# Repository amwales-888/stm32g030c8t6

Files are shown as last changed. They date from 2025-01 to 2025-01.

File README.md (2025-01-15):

# stm32g030c8t6
Simple breakout board for stm32g030c8t6

- 3.3v LDO powered from 5V USB.
- UART connectivity to USB via ch340 optionally connected to pins PA9/PA10 using jumpers.
- ARM SWD programming interface header.
- All other pins are broken out to headers.
- 1 LEDS optionally connected to pin PB0 using jumper.
- 1 Button with pulldown optionally connected to pin PB1 using jumper.
- 1 Button connected to RESET pin, pulled high.

<table>
  <tr>
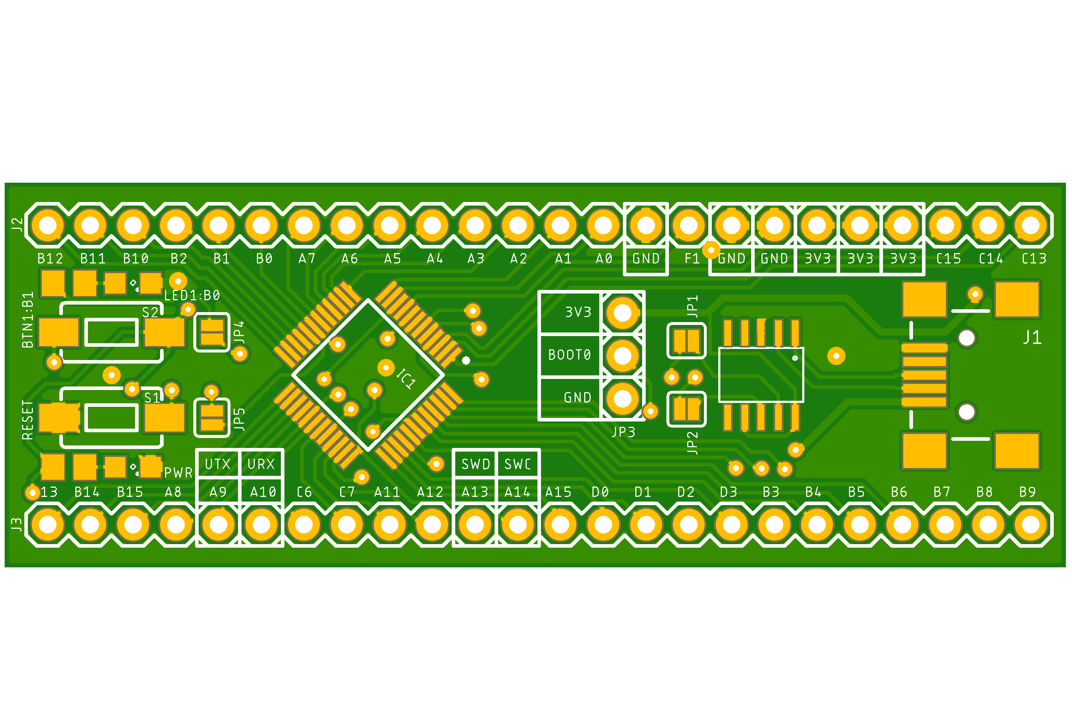
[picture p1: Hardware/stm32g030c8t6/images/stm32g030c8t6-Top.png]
    <td> </td>
  </tr>
  <tr>
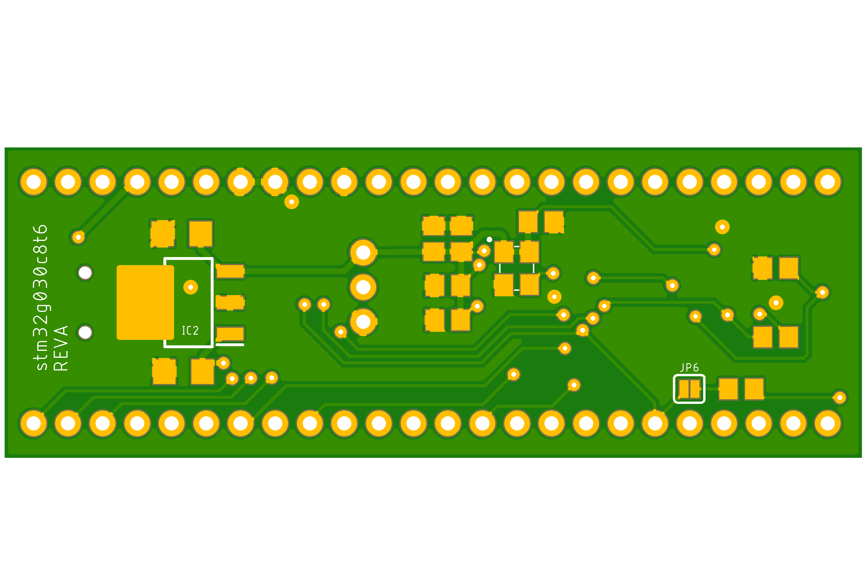
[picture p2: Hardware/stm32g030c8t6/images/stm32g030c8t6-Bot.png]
    <td> </td>
  </tr>
</table>

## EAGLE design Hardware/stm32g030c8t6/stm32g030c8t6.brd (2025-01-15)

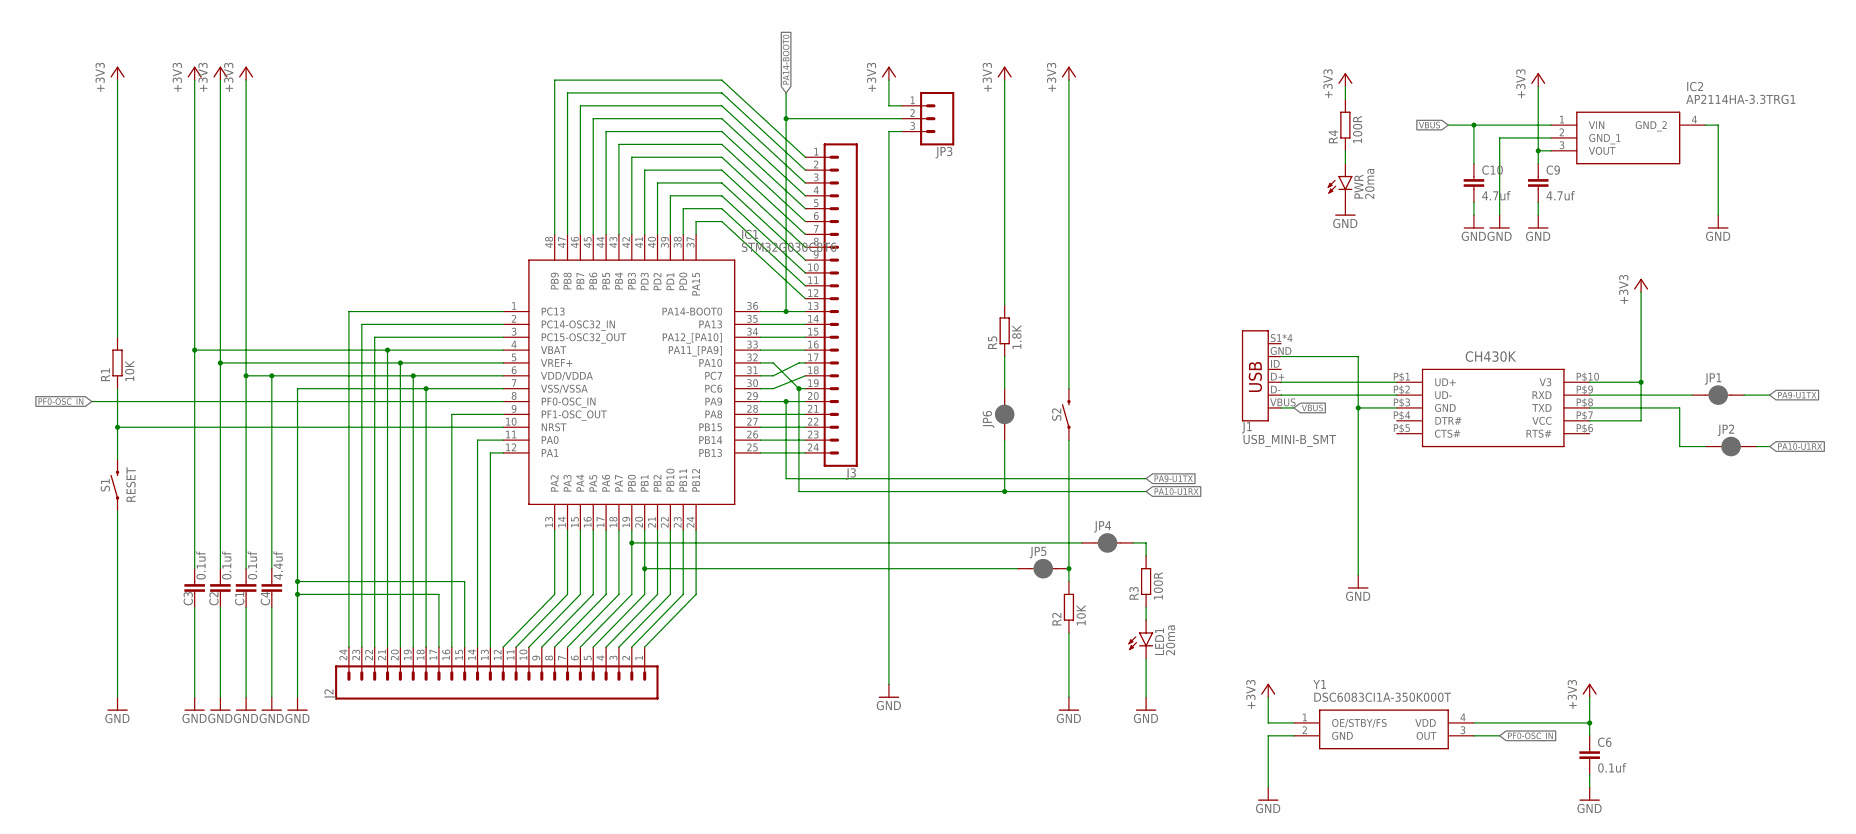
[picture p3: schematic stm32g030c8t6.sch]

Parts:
C1, C2, C3, C6: 0.1uf; C0805
C4: 4.4uf; C0805
C9, C10: 4.7uf; C1206
IC1: STM32G030C8T6; QFP50P900X900X160-48N
IC2: AP2114HA-3.3TRG1; SOT230P700X180-4N
J1: USB_MINI-B_SMT; USB-MINIB
J2, J3: CONN_24; 1X24
JP1, JP2, JP4, JP5, JP6: JUMPER-SMT_2_NC_PASTE_SILK; SMT-JUMPER_2_NC_PASTE_SILK
JP3: 455-1750-1-ND; 1X03
LED1: 20ma; SML0805
PWR: 20ma; SML0805
R1, R2: 10K; R0805
R3, R4: 100R; R0805
R5: 1.8K; R0805
S1, S2: RESET; TACTILE_SWITCH_SMD_6.0X3.5MM
U$1: CH430K; ESSOP-10
Y1: DSC6083CI1A-350K000T; DSC6083CI1A350K000T

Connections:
+3V3: C1.1, C2.1, C3.1, C4.1, C6.1, C9.1, IC1.4 (VBAT), IC1.5 (VREF+), IC1.6 (VDD/VDDA), IC2.3 (VOUT), J2.19, J2.20, J2.21, JP3.1, R1.2, R4.2, R5.2, S2.2, U$1.P$7 (VCC), U$1.P$10 (V3), Y1.1 (OE/STBY/FS), Y1.4 (VDD)
A0: IC1.11 (PA0), J2.14
A1: IC1.12 (PA1), J2.13
A2: IC1.13 (PA2), J2.12
A3: IC1.14 (PA3), J2.11
A4: IC1.15 (PA4), J2.10
A5: IC1.16 (PA5), J2.9
A6: IC1.17 (PA6), J2.8
A7: IC1.18 (PA7), J2.7
B0: IC1.19 (PB0), J2.6, JP4.1
B1: IC1.20 (PB1), J2.5, JP5.1
B2: IC1.21 (PB2), J2.4
B10: IC1.22 (PB10), J2.3
B11: IC1.23 (PB11), J2.2
B12: IC1.24 (PB12), J2.1
GND: C1.2, C2.2, C3.2, C4.2, C6.2, C9.2, C10.2, IC1.7 (VSS/VSSA), IC2.2 (GND_1), IC2.4 (GND_2), J1.GND, J2.15, J2.17, J2.18, JP3.3, LED1.C, PWR.C, R2.1, S1.1, U$1.P$3 (GND), Y1.2 (GND)
unnamed: JP6.2, R5.1
unnamed: LED1.A, R3.1
unnamed: JP4.2, R3.2
unnamed: JP5.2, R2.2, S2.1
unnamed: PWR.A, R4.1
PA8: IC1.28 (PA8), J3.21
PA9-U1TX: IC1.29 (PA9), J3.20, JP1.2
PA10-U1RX: IC1.32 (PA10), J3.19, JP2.2, JP6.1
PA11: IC1.33 (PA11_[PA9]), J3.16
PA12: IC1.34 (PA12_[PA10]), J3.15
PA13: IC1.35 (PA13), J3.14
PA14-BOOT0: IC1.36 (PA14-BOOT0), J3.13, JP3.2
PA15: IC1.37 (PA15), J3.12
PB3: IC1.42 (PB3), J3.7
PB4: IC1.43 (PB4), J3.6
PB5: IC1.44 (PB5), J3.5
PB6: IC1.45 (PB6), J3.4
PB7: IC1.46 (PB7), J3.3
PB8: IC1.47 (PB8), J3.2
PB9: IC1.48 (PB9), J3.1
PB13: IC1.25 (PB13), J3.24
PB14: IC1.26 (PB14), J3.23
PB15: IC1.27 (PB15), J3.22
PC6: IC1.30 (PC6), J3.18
PC7: IC1.31 (PC7), J3.17
PC13: IC1.1 (PC13), J2.24
PC14: IC1.2 (PC14-OSC32_IN), J2.23
PC15: IC1.3 (PC15-OSC32_OUT), J2.22
PD0: IC1.38 (PD0), J3.11
PD1: IC1.39 (PD1), J3.10
PD2: IC1.40 (PD2), J3.9
PD3: IC1.41 (PD3), J3.8
PF0-OSC_IN: IC1.8 (PF0-OSC_IN), Y1.3 (OUT)
PF1: IC1.9 (PF1-OSC_OUT), J2.16
PF2-NRST: IC1.10 (NRST), R1.1, S1.2
RXD: JP1.1, U$1.P$9 (RXD)
TXD: JP2.1, U$1.P$8 (TXD)
USB_N: J1.D-, U$1.P$2 (UD-)
USB_P: J1.D+, U$1.P$1 (UD+)
VBUS: C10.1, IC2.1 (VIN), J1.VBUS

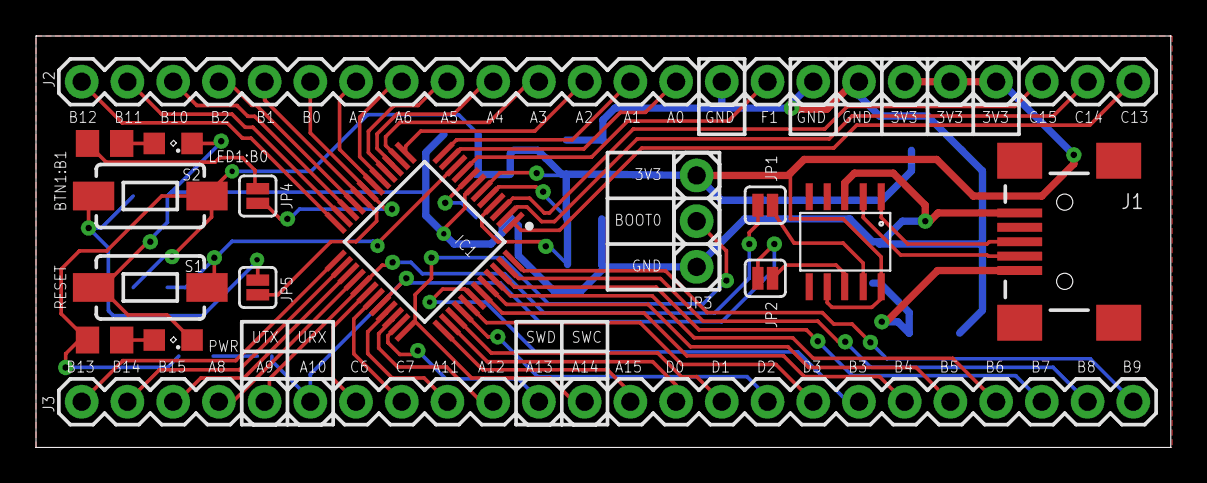
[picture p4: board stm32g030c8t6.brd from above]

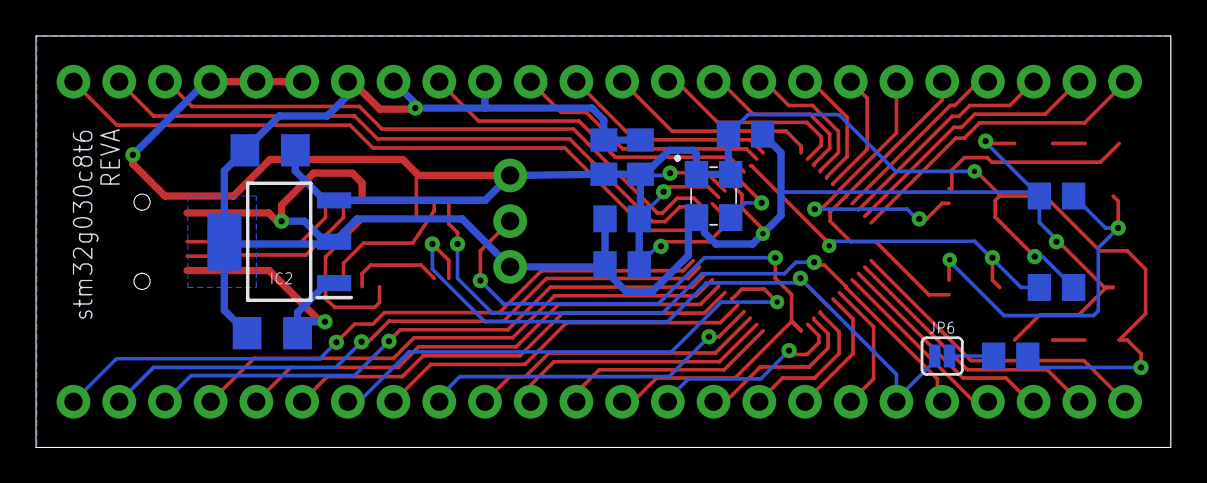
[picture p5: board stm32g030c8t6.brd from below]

Board: 2 copper layers, 63.0 x 22.9 mm, 29 parts (13 on the bottom side), 56 nets.

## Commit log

2024-10-29 Initial checkin
    [copper_bottom.gbr, copper_top.gbr, drill_1_16.xln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]
2025-01-15 Added pullup to RX pin
    [stm32g030c8t6.brd, stm32g030c8t6.sch]
2025-01-15 associated bord/schematic with eagle project
2025-01-15 Tidyup schematic, silkscreen, regenerate gerbers and images
    [copper_bottom.gbr, copper_top.gbr, drill_1_16.xln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]

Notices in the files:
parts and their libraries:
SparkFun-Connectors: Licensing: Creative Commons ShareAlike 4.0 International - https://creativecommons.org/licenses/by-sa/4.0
